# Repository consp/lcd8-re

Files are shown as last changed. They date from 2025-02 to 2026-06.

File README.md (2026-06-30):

# Gui based on lvgl9 for eBikes using a VESC motor controller 

Features:
* customisable (obviously ...)
* Faster update rates than any factory device
* Uses LVGL
* Has MCU with sufficient power and memory to do everything I want it to without too much problems.

## who is this for?

Anyone who wants to build their own eBike display and wants an example. This project is provided as is. No commercial usage is allowed of any kind unless stated explicitly otherwise.

### Who is this not for?

Anyone who expects a ready made product without effort.

## Supported platforms 

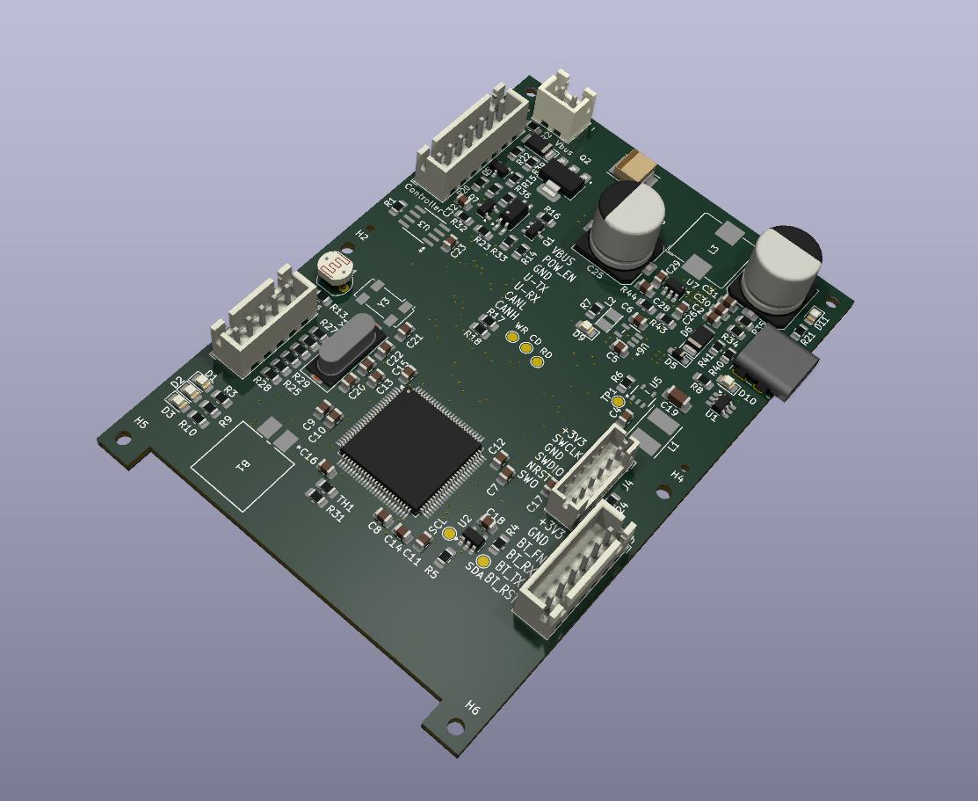
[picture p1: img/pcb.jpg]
Schematic

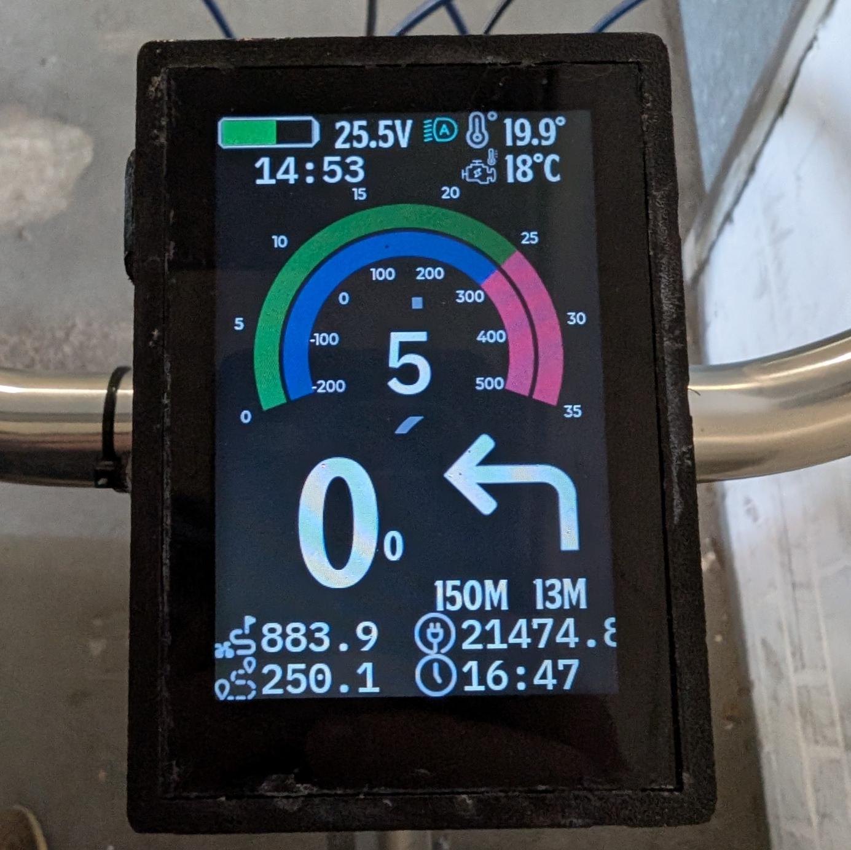
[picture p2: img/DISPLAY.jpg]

- Custom display:
  - Transflective LCD
  - 4 button support
  - Persistent Real time clock (if battery added) 
  - CAN/UART capable
  - Fast
  - Be able to connect to phone to show nav updates (via custom [gadgetbridge app](https://github.com/consp/Gadgetbridge))
  - Connect and use VESC messages ([custom version needed](https://github.com/consp/bldc), [custom tooling needed](https://github.com/consp/vesc-tool))
  - STM32H743
  - Should have enough power to output 1.5A on the 5V rail to USB

## Known issues
Probably many, there is a bug in the PCB making the ADC unreliable when a battery is installed.

# Attribution
Temperature icon: [Temperature Vectors by Vecteezy](https://www.vecteezy.com/free-vector/temperature)
Engine icon: [Heat icons created by HAJICON - Flaticon](https://www.flaticon.com/free-icons/heatv)
Brake icon: [Brake icons created by Smashicons - Flaticon](https://www.flaticon.com/free-icons/brake)
Trip icon: [Trip icons created by improstudio - Flaticon](https://www.flaticon.com/free-icons/trip)
Other icons: [Uicons - Flaticon](https://www.flaticon.com/uicons)
Headlight and headlight auto: [Headlight icons created by TravisAvery - Flaticon](https://www.flaticon.com/free-icon/headlights_9104236)

# License
All stuff not already licenced otherwise is only available under CC-BY-NC-4.0 https://creativecommons.org/licenses/by-nc/4.0/ . For commercial use contact me. No waranty of any kind is provided. No claims of any kind can be made.

# Contribution

If, for some reason, you want to add something or make a pull request: It's fine to do so but don't expect a prompt response. Any LLM based code or other generated files will be rejected without warning.
If, for some reason, you have a question: Use the discussion part of github. Do not expect a prompt response.

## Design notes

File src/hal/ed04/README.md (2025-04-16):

* Mediatek 2502cv 
* GigaDevice HJHJ2115

Pinout buttons

top right view male head on
1 - primary blue - shorts to green

KT unit:

Groen geel zwart rood, Geel groen zwart blauw rood

Rood zwart geel groen blauw

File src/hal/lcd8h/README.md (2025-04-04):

# LCD8 reverse engineering project

Since my LCD8 device fell appart due to the plastic becomming brittile (I guess it's not proper ABS, I'm switching to a bafang anyway) I decided to open it up and see what's going on.

In the end I'm writing my own firmware for it because reasons.

## Board
Front:
Front of PCB
Back:
Back of PCB

### Chips

- U1: MCU AT32F415RCT7, 256k flash
- U2: C1117-3.3 3.3v LDO
- U3: XLSEMI XL7015E1 DC/DC converter 0.8A 5-80V
- U4: 1B0B0G Unknown IC, ~~likely~~ a I2C EEPROM (512 bytes) acts like a standard EEPROM with 2 byte read and 3 byte write. Address is 0x50 looking at the first byte. Only page 1 is ever read.

- Qn: Either G1 or BG (NPN or PNP fet)
- Q?: A1013 PNP Transistor (schematic is wrong), 1A -160V. 

### Notable things
- Beware! The Electrolithic caps might be snot-glued in.
- Bodge cap just north of the MCU
- Place for one more cap on power input on the DC/DC converter.
- Place for one more cap on both VDD and +5V.
- Unconnected 2 pin connector connected to PC0, likely for a non installed button. You could use it for a light sensor as PC0 is an ADC channel.
- Two large pads connected to GND/VBAT, on the USB versions this is where the USB DC/DC converter is connected.
- Two small pads connected by zener to GND/VDD, likely to supply the chip if a RTC low freq. crystal is provided or by using the CINT clock.
- There is a NTC inside the button pcb on channel PC1 (could also be PC2 if installed upside down). It's read normally and acts as a button when pulled to ground.
- Power enable is a very simple "press button and get power", after which the MCU takes over by triggering PA4 (sense for on button is on PA6). This also means the button is at VBAT and the inputs of the other buttons are not protected so make sure they do not short out.
- Power enable will not work with an external sink (e.g. a debugger) attached. 
- The MCU does not like to be power glitched. This will destroy any data in flash memory. (experimentally verified, repeatedly)

- The clock calibration of the internal clock is nonexistant (probably never done), resulting in a 27% in my case (running slow). This also messes up the baudrate calculation and anything over 57k6 will result in bit errors which is probably the reason they stuck with 9k6. Adjusting for this allows higher baudrates.
- To achieve any baudrates over 9k6 you also need to remove the bodgecap added to the RX line. If the baudrate is properly set (or within about 1%) it is never needed anyway.

## Display
The display has the following characteristics:
- 320x480 pixels
- 8080 interface with a ILI9488 chip as display driver.
- 16bit parallel i8080 bus
- 256k colors, recommended to use 64k as the bus is 16bit.

Pinout control lines:
- Pin 9 (PC11) is CS
- Pin 10 (PC10) is DCx (Data/Command select)
- Pin 11 (PC9) is Write Strobe (WRx)
- Pin 12 (PC8) is Read Strobe (RDx)

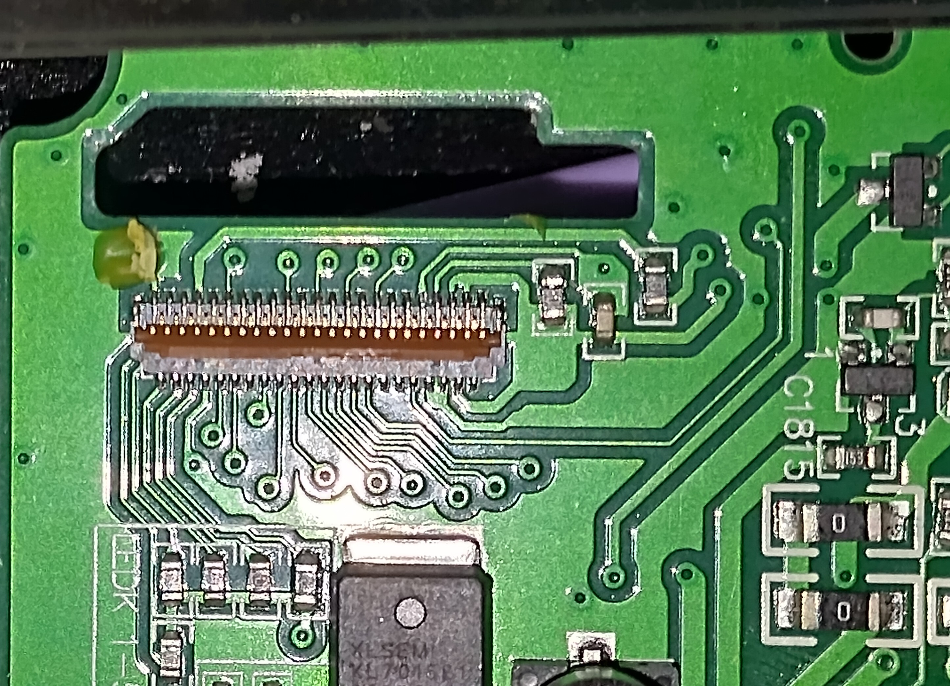
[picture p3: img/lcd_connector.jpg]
LCD connector


Markings display: 
- LM35014B2
- HCC350-06A29
- LM-035CK45021N0-14B2-B1

Markings connector:
- MCU 16B
- RGB 16/18
- BJG-035CK4502N0

The CS is not needed but used by the original firmware. The source contains the gamma setup input copied via logic analyser. The original firmware never reads from the chip but the lines are attached and work.
With no delay states from the MCU the ILI9488 can do ~10MHz when pushing data from memory (~10ns write burst, 90ns delay). In practice it is less but still about 4x the speed of the original firmware.

## Software
The MCU is locked, writing will destroy the original data. BEWARE!

* LVGL 8.4 for most gui parts, can be used 9.x uses a lot more memory resulting is possible tearing (the framebuffer is 32 lines and less results in partial writes of components).
* Raw write for the large letters as lvgl will make buffers for them which eat all the memory (which is not needed anyway).

## Schematic
My poor attempt at drawing a schematic.
Schematic

# License
All stuff not already licenced otherwise is only available under CC-BY-NC-4.0 https://creativecommons.org/licenses/by-nc/4.0/ . For commercial use contact me.

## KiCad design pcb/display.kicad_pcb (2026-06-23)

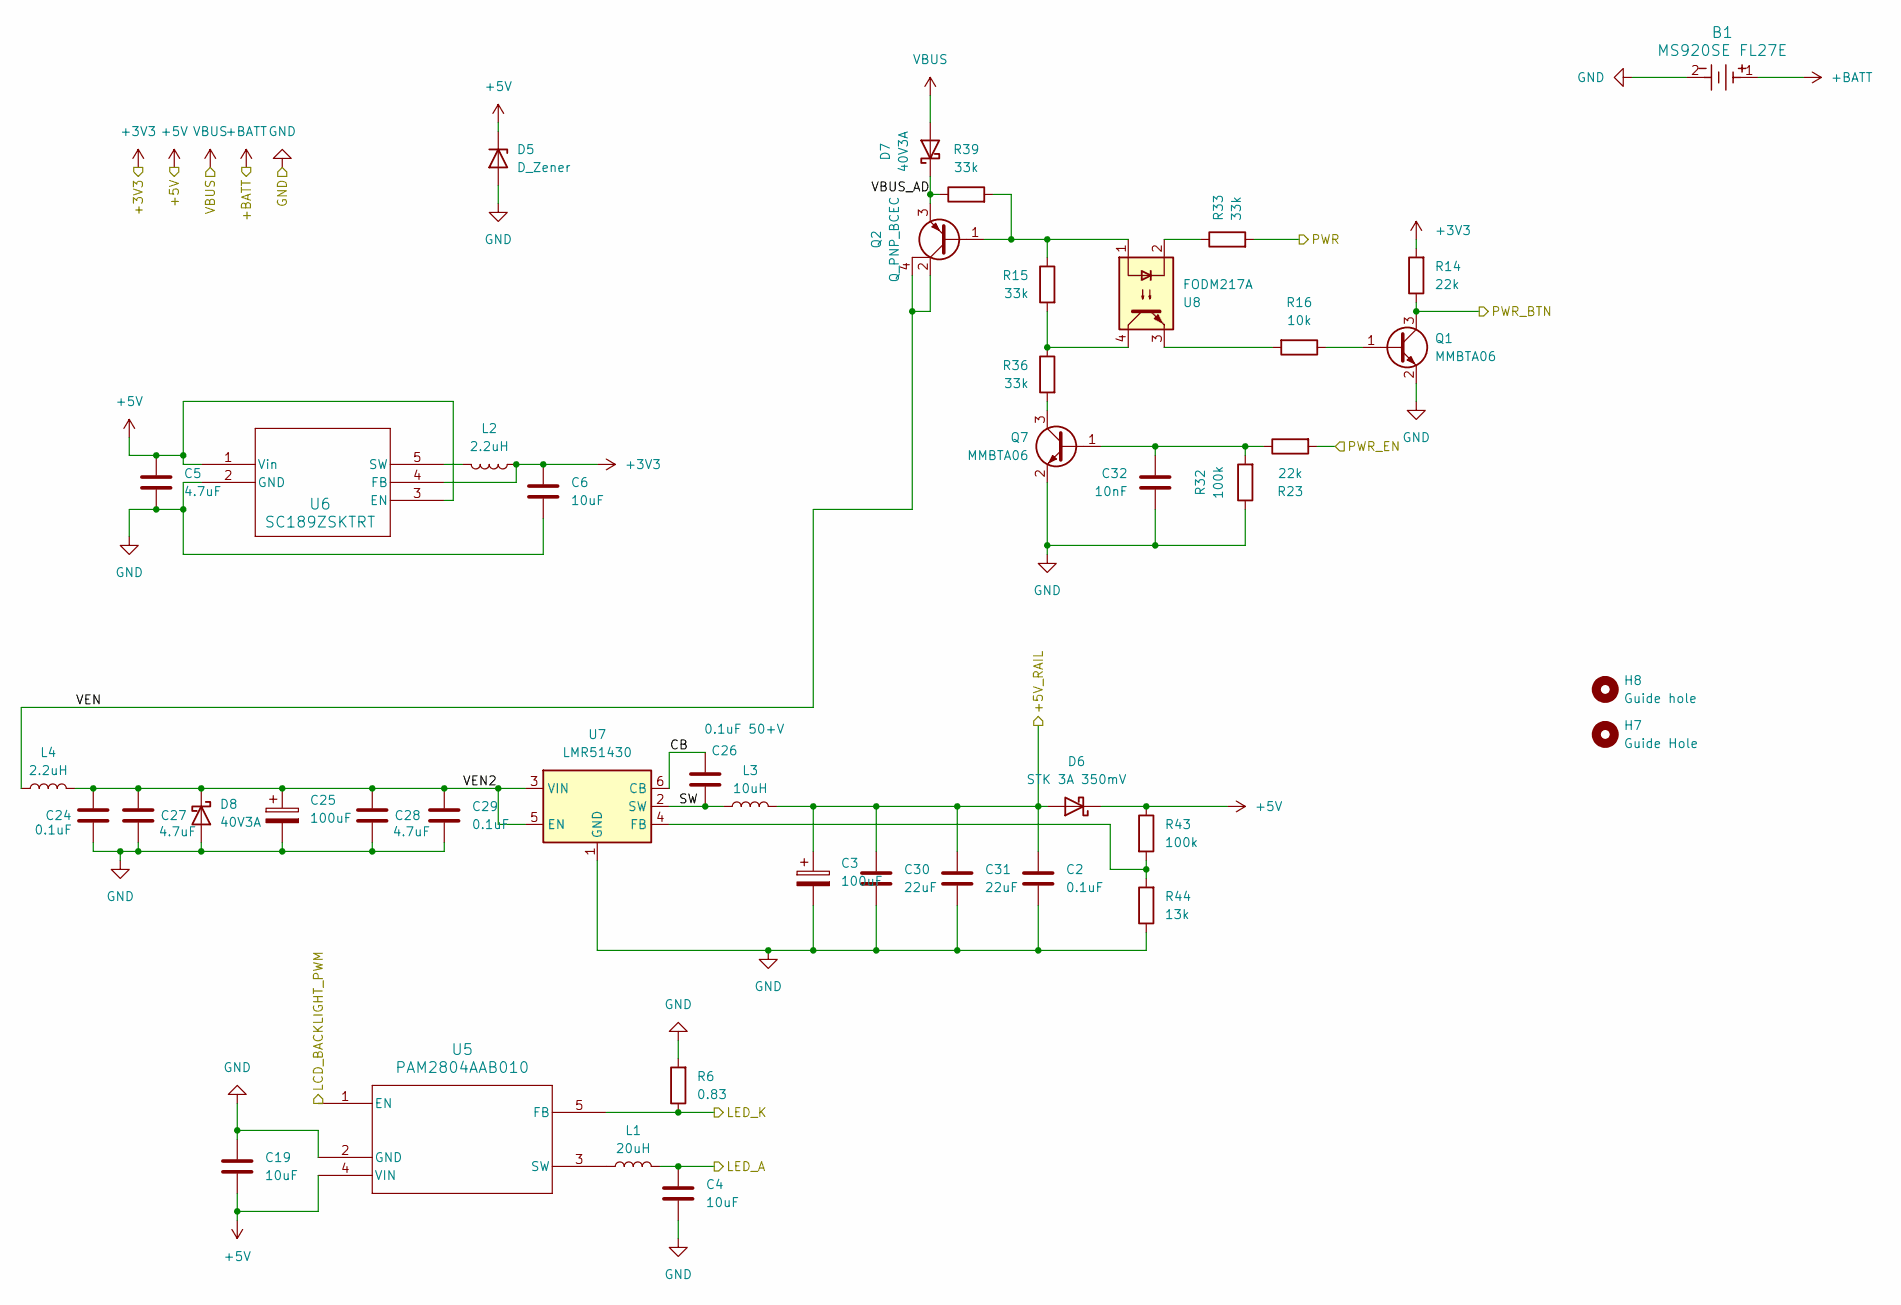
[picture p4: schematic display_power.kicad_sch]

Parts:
B1: MS920SE FL27E; BATT_MS920SE_FL27E_SEI
C2: 0.1uF; C_0805_2012Metric
C3, C25: 100uF; CP_Elec_10x10.5
C4, C6: 10uF; C_0805_2012Metric
C5: 4.7uF; C_0805_2012Metric
C19: 10uF; C_1206_3216Metric_Pad1.33x1.80mm_HandSolder
C24, C29: 0.1uF; C_0805_2012Metric_Pad1.18x1.45mm_HandSolder
C26: 0.1uF 50+V; C_0805_2012Metric_Pad1.18x1.45mm_HandSolder
C27, C28: 4.7uF; C_0805_2012Metric_Pad1.18x1.45mm_HandSolder
C30, C31: 22uF; C_0805_2012Metric_Pad1.18x1.45mm_HandSolder
C32: 10nF; C_0805_2012Metric
D5: D_Zener; D_SOD-323_HandSoldering
D6: STK 3A 350mV; D_SOD-128
D7: 40V3A; D_SOD-128
D8: 40V3A; D_SOD-123
H7: Guide Hole; ToolingHole_1.152mm
H8: Guide hole; ToolingHole_1.152mm
L1: 20uH; L_Taiyo-Yuden_NR-50xx_HandSoldering
L2: 2.2uH; L_Taiyo-Yuden_NR-20xx_HandSoldering
L3: 10uH; L_Bourns_SRP1038C_10.0x10.0mm
L4: 2.2uH; L_Taiyo-Yuden_NR-50xx_HandSoldering
Q1, Q7: MMBTA06; SOT-23
Q2: Q_PNP_BCEC; SOT-223-3_TabPin2
R6: 0.83; R_0805_2012Metric_Pad1.20x1.40mm_HandSolder
R14, R23: 22k; R_0805_2012Metric_Pad1.20x1.40mm_HandSolder
R15, R33, R36, R39: 33k; R_0805_2012Metric_Pad1.20x1.40mm_HandSolder
R16: 10k; R_0805_2012Metric_Pad1.20x1.40mm_HandSolder
R32, R43: 100k; R_0805_2012Metric_Pad1.20x1.40mm_HandSolder
R44: 13k; R_0805_2012Metric_Pad1.20x1.40mm_HandSolder
U5: PAM2804AAB010; PAM2804_DIO
U6: SC189ZSKTRT; MF05A_TEX
U7: LMR51430; SOT-23-6
U8: FODM217A; SOP-4_4.4x2.6mm_P1.27mm

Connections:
+3V3: C6.1, L2.1, R14.2, U6.4 (FB); also elsewhere on the board
+5V: C5.1, C19.2, D5.1 (K), D6.1 (K), R43.1, U5.4 (VIN), U6.1 (Vin), U6.3 (EN); also elsewhere on the board
+BATT: B1.1; also elsewhere on the board
/Connectors/LED_A: C4.1, L1.2; also elsewhere on the board
/Connectors/LED_K: R6.1, U5.5 (FB); also elsewhere on the board
/Connectors/PWR: R33.2; also elsewhere on the board
/MCU/LCD_BACKLIGHT_PWM: U5.1 (EN); also elsewhere on the board
/MCU/PWR_BTN: Q1.3 (C), R14.1; also elsewhere on the board
/MCU/PWR_EN: R23.2; also elsewhere on the board
/Other/+5V_RAIL: C2.1, C3.1, C30.1, C31.1, D6.2 (A), L3.2; also elsewhere on the board
/Power/CB: C26.1, U7.6 (CB)
/Power/SW: C26.2, L3.1, U7.2 (SW)
/Power/VBUS_AD: D7.1 (K), Q2.3 (E), R39.1
/Power/VEN: L4.1, Q2.2 (C), Q2.4 (C)
/Power/VEN2: C24.1, C25.1, C27.1, C28.1, C29.1, D8.1 (K), L4.2, U7.3 (VIN), U7.5 (EN)
GND: B1.2, C2.2, C3.2, C4.2, C5.2, C6.2, C19.1, C24.2, C25.2, C27.2, C28.2, C29.2, C30.2, C31.2, C32.2, D5.2 (A), D8.2 (A), Q1.2 (E), Q7.2 (E), R6.2, R32.1, R44.1, U5.2 (GND), U6.2 (GND), U7.1 (GND); also elsewhere on the board
unnamed: Q1.1 (B), R16.1
unnamed: Q2.1 (B), R15.1, R39.2, U8.1
unnamed: C32.1, Q7.1 (B), R23.1, R32.2
unnamed: Q7.3 (C), R36.2
unnamed: R15.2, R36.1, U8.4
unnamed: R16.2, U8.3
unnamed: R33.1, U8.2
unnamed: L1.1, U5.3 (SW)
unnamed: L2.2, U6.5 (SW)
unnamed: R43.2, R44.2, U7.4 (FB)
VBUS: D7.2 (A); also elsewhere on the board

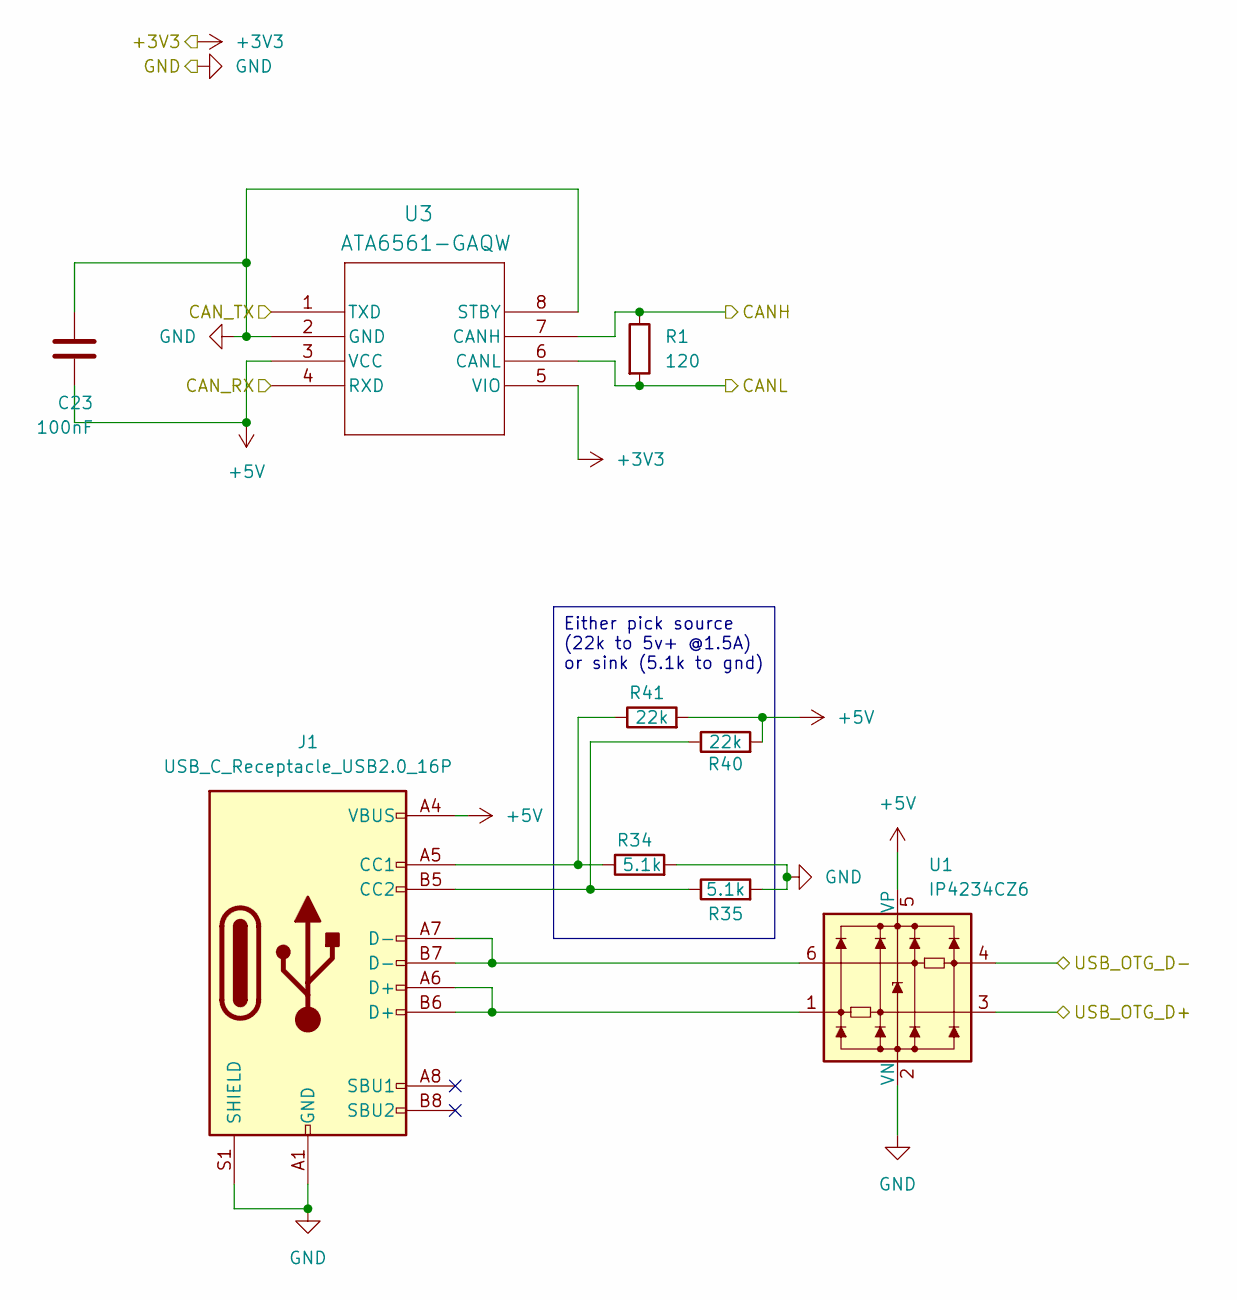
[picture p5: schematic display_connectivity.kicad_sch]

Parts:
C23: 100nF; C_0805_2012Metric
J1: USB_C_Receptacle_USB2.0_16P; USB_C_Receptacle_GCT_USB4085
R1: 120; R_0805_2012Metric_Pad1.20x1.40mm_HandSolder
R34, R35: 5.1k; R_0805_2012Metric
R40, R41: 22k; R_0805_2012Metric
U1: IP4234CZ6; SC-74-6_1.55x2.9mm_P0.95mm
U3: ATA6561-GAQW; SOIC8_4P9X3P9MC_MCH

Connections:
+3V3: U3.5 (VIO); also elsewhere on the board
+5V: C23.1, J1.A4 (VBUS), J1.A9 (VBUS), J1.B4 (VBUS), J1.B9 (VBUS), R40.2, R41.2, U1.5 (VP), U3.3 (VCC); also elsewhere on the board
/Connectivity/CANH: R1.1, U3.7 (CANH); also elsewhere on the board
/Connectivity/CANL: R1.2, U3.6 (CANL); also elsewhere on the board
/Connectivity/CAN_RX: U3.4 (RXD); also elsewhere on the board
/Connectivity/CAN_TX: U3.1 (TXD); also elsewhere on the board
/Connectivity/USB_OTG_D+: U1.3; also elsewhere on the board
/Connectivity/USB_OTG_D-: U1.4; also elsewhere on the board
GND: C23.2, J1.A1 (GND), J1.A12 (GND), J1.B1 (GND), J1.B12 (GND), J1.S1 (SHIELD), R34.2, R35.2, U1.2 (VN), U3.2 (GND), U3.8 (STBY); also elsewhere on the board
unnamed: J1.A5 (CC1), R34.1, R41.1
unnamed: J1.B5 (CC2), R35.1, R40.1
unnamed: J1.A6 (D+), J1.B6 (D+), U1.1
unnamed: J1.A7 (D-), J1.B7 (D-), U1.6

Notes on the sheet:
Either pick source (22k to 5v+ @1.5A) or sink (5.1k to gnd)

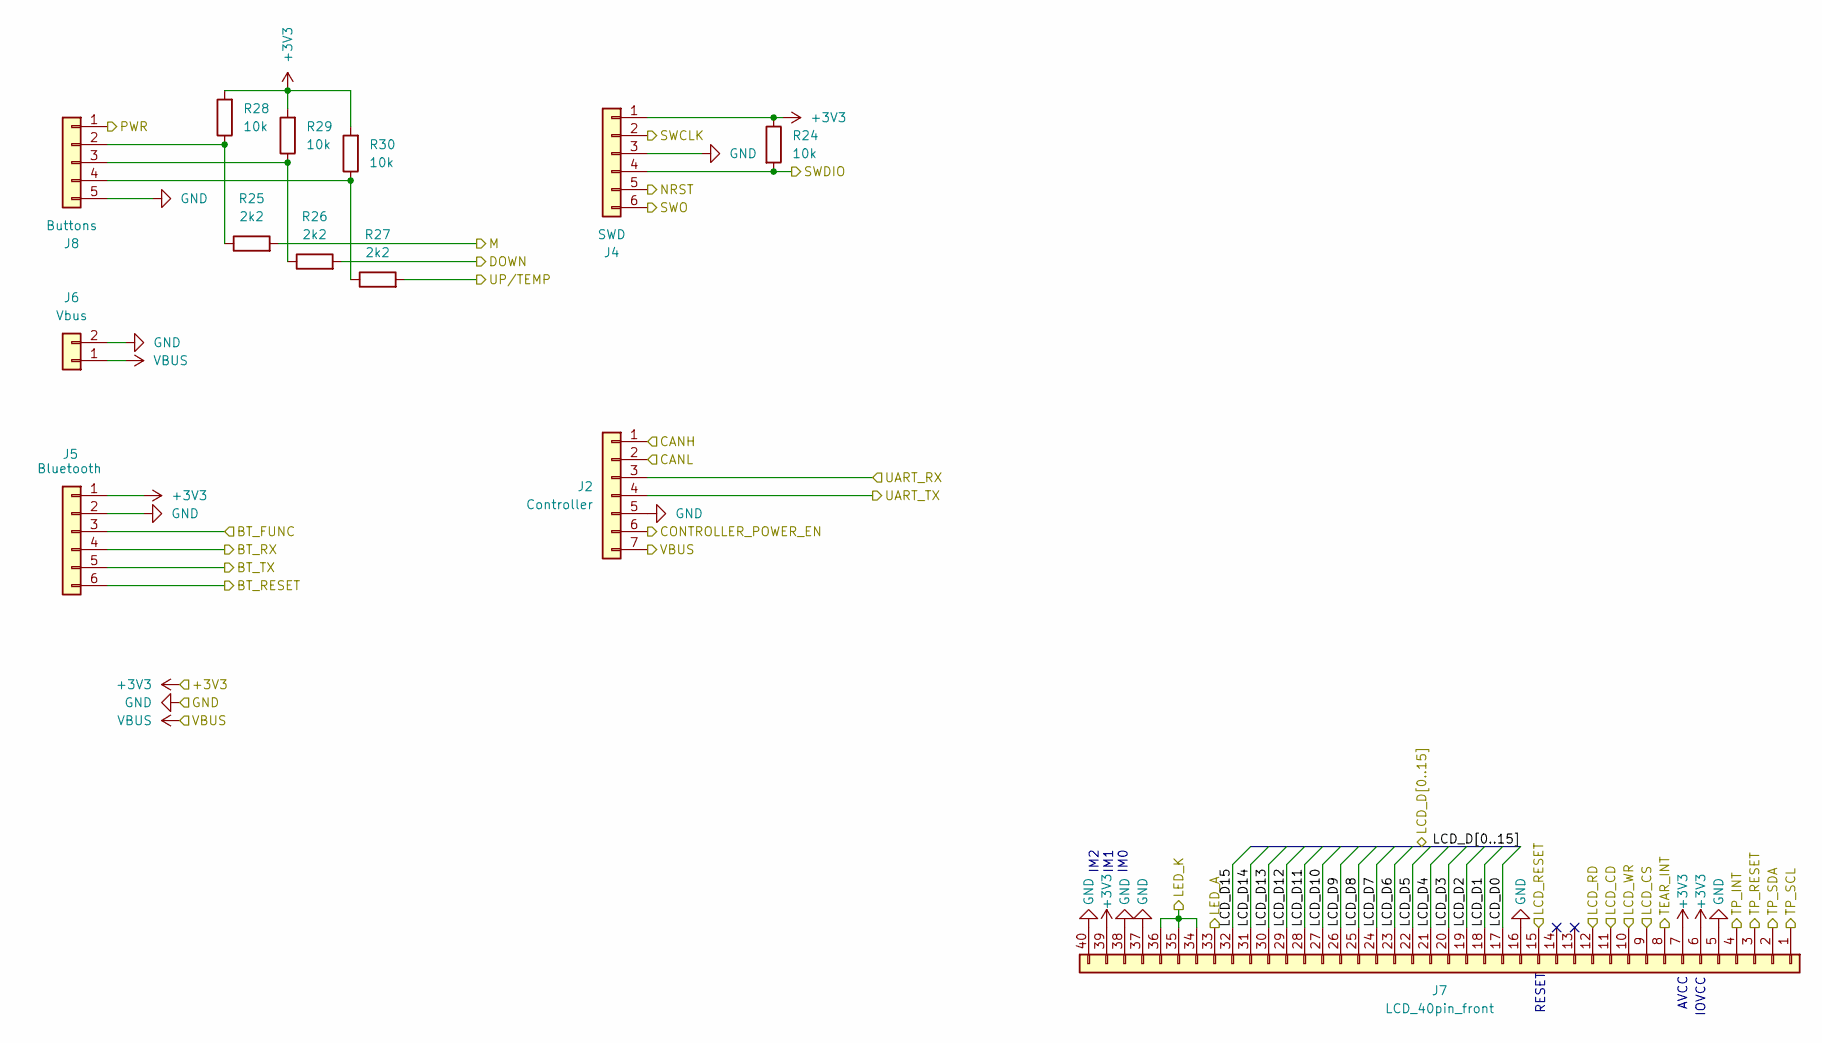
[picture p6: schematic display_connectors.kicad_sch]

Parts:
J2: Controller; JST_XH_B7B-XH-A_1x07_P2.50mm_Vertical
J4: SWD; JST_PH_B6B-PH-K_1x06_P2.00mm_Vertical
J5: Bluetooth; JST_XH_B6B-XH-A_1x06_P2.50mm_Vertical
J6: Vbus; JST_XH_B2B-XH-A_1x02_P2.50mm_Vertical
J7: LCD_40pin_front; Hirose_FH12-40S-0.5SH_1x40-1MP_P0.50mm_Horizontal
J8: Buttons; JST_XH_B5B-XH-A_1x05_P2.50mm_Vertical
R24, R28, R29, R30: 10k; R_0805_2012Metric_Pad1.20x1.40mm_HandSolder
R25, R26, R27: 2k2; R_0805_2012Metric_Pad1.20x1.40mm_HandSolder

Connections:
+3V3: J4.1, J5.1, J7.6, J7.7, J7.39, R24.1, R28.2, R29.2, R30.2; also elsewhere on the board
/Connectivity/CANH: J2.1; also elsewhere on the board
/Connectivity/CANL: J2.2; also elsewhere on the board
/Connectors/BT_FUNC: J5.3; also elsewhere on the board
/Connectors/BT_RESET: J5.6; also elsewhere on the board
/Connectors/BT_RX: J5.4; also elsewhere on the board
/Connectors/BT_TX: J5.5; also elsewhere on the board
/Connectors/CONTROLLER_POWER_EN: J2.6; also elsewhere on the board
/Connectors/LCD_CS: J7.9; also elsewhere on the board
/Connectors/LCD_D0: J7.17; also elsewhere on the board
/Connectors/LCD_D1: J7.18; also elsewhere on the board
/Connectors/LCD_D2: J7.19; also elsewhere on the board
/Connectors/LCD_D3: J7.20; also elsewhere on the board
/Connectors/LCD_D4: J7.21; also elsewhere on the board
/Connectors/LCD_D5: J7.22; also elsewhere on the board
/Connectors/LCD_D6: J7.23; also elsewhere on the board
/Connectors/LCD_D7: J7.24; also elsewhere on the board
/Connectors/LCD_D8: J7.25; also elsewhere on the board
/Connectors/LCD_D9: J7.26; also elsewhere on the board
/Connectors/LCD_D10: J7.27; also elsewhere on the board
/Connectors/LCD_D11: J7.28; also elsewhere on the board
/Connectors/LCD_D12: J7.29; also elsewhere on the board
/Connectors/LCD_D13: J7.30; also elsewhere on the board
/Connectors/LCD_D14: J7.31; also elsewhere on the board
/Connectors/LCD_D15: J7.32; also elsewhere on the board
/Connectors/LED_A: J7.33; also elsewhere on the board
/Connectors/LED_K: J7.34, J7.35, J7.36; also elsewhere on the board
/Connectors/PWR: J8.1; also elsewhere on the board
/Connectors/SWCLK: J4.2; also elsewhere on the board
/Connectors/SWDIO: J4.4, R24.2; also elsewhere on the board
/Connectors/SWO: J4.6; also elsewhere on the board
/Connectors/TEAR_INT: J7.8; also elsewhere on the board
/Connectors/TP_INT: J7.4; also elsewhere on the board
/Connectors/TP_RESET: J7.3; also elsewhere on the board
/Connectors/TP_SCL: J7.1; also elsewhere on the board
/Connectors/TP_SDA: J7.2; also elsewhere on the board
/Connectors/UART_RX: J2.3; also elsewhere on the board
/Connectors/UART_TX: J2.4; also elsewhere on the board
/MCU/DOWN: R26.2; also elsewhere on the board
/MCU/LCD_CD: J7.11; also elsewhere on the board
/MCU/LCD_RD: J7.12; also elsewhere on the board
/MCU/LCD_WR: J7.10; also elsewhere on the board
/MCU/M: R25.2; also elsewhere on the board
/MCU/NRST: J4.5, J7.15; also elsewhere on the board
/MCU/UP/TEMP: R27.2; also elsewhere on the board
GND: J2.5, J4.3, J5.2, J6.2, J7.5, J7.16, J7.37, J7.38, J7.40, J8.5; also elsewhere on the board
unnamed: J8.2, R25.1, R28.1
unnamed: J8.3, R26.1, R29.1
unnamed: J8.4, R27.1, R30.1
VBUS: J2.7, J6.1; also elsewhere on the board

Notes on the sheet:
AVCC
RESET
IOVCC
IM2 IM1 IM0

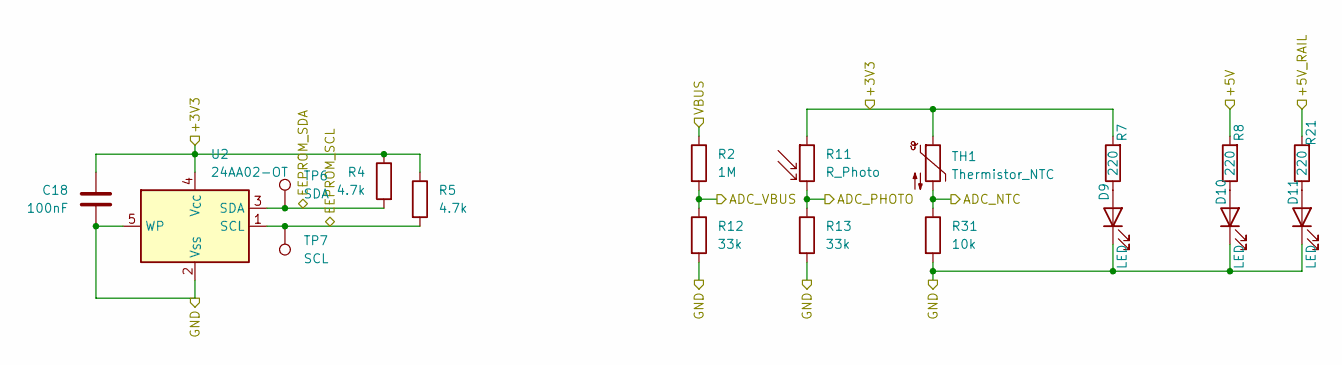
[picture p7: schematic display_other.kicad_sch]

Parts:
C18: 100nF; C_0805_2012Metric
D9, D10, D11: LED; LED_0805_2012Metric_Pad1.15x1.40mm_HandSolder
R2: 1M; R_0805_2012Metric_Pad1.20x1.40mm_HandSolder
R4, R5: 4.7k; R_0805_2012Metric_Pad1.20x1.40mm_HandSolder
R7, R8, R21: 220; R_0805_2012Metric_Pad1.20x1.40mm_HandSolder
R11: R_Photo; R_LDR_5.1x4.3mm_P3.4mm_Vertical
R12, R13: 33k; R_0805_2012Metric_Pad1.20x1.40mm_HandSolder
R31: 10k; R_0805_2012Metric_Pad1.20x1.40mm_HandSolder
TH1: Thermistor_NTC; R_0805_2012Metric_Pad1.20x1.40mm_HandSolder
TP6: SDA; TestPoint_Pad_D1.5mm
TP7: SCL; TestPoint_Pad_D1.5mm
U2: 24AA02-OT; SOT-23-5

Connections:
+3V3: C18.2, R4.1, R5.1, R7.2, R11.1, TH1.1, U2.4 (V_{CC}); also elsewhere on the board
+5V: R8.2; also elsewhere on the board
/MCU/ADC_NTC: R31.1, TH1.2; also elsewhere on the board
/MCU/ADC_VBUS: R2.2, R12.1; also elsewhere on the board
/MCU/ADH_PHOTO: R11.2, R13.1; also elsewhere on the board
/MCU/EEPROM_SCA: R4.2, TP6.1, U2.3 (SDA); also elsewhere on the board
/MCU/EEPROM_SCL: R5.2, TP7.1, U2.1 (SCL); also elsewhere on the board
/Other/+5V_RAIL: R21.2; also elsewhere on the board
GND: C18.1, D9.1 (K), D10.1 (K), D11.1 (K), R12.2, R13.2, R31.2, U2.2 (V_{SS}), U2.5 (WP); also elsewhere on the board
unnamed: D9.2 (A), R7.1
unnamed: D10.2 (A), R8.1
unnamed: D11.2 (A), R21.1
VBUS: R2.1; also elsewhere on the board

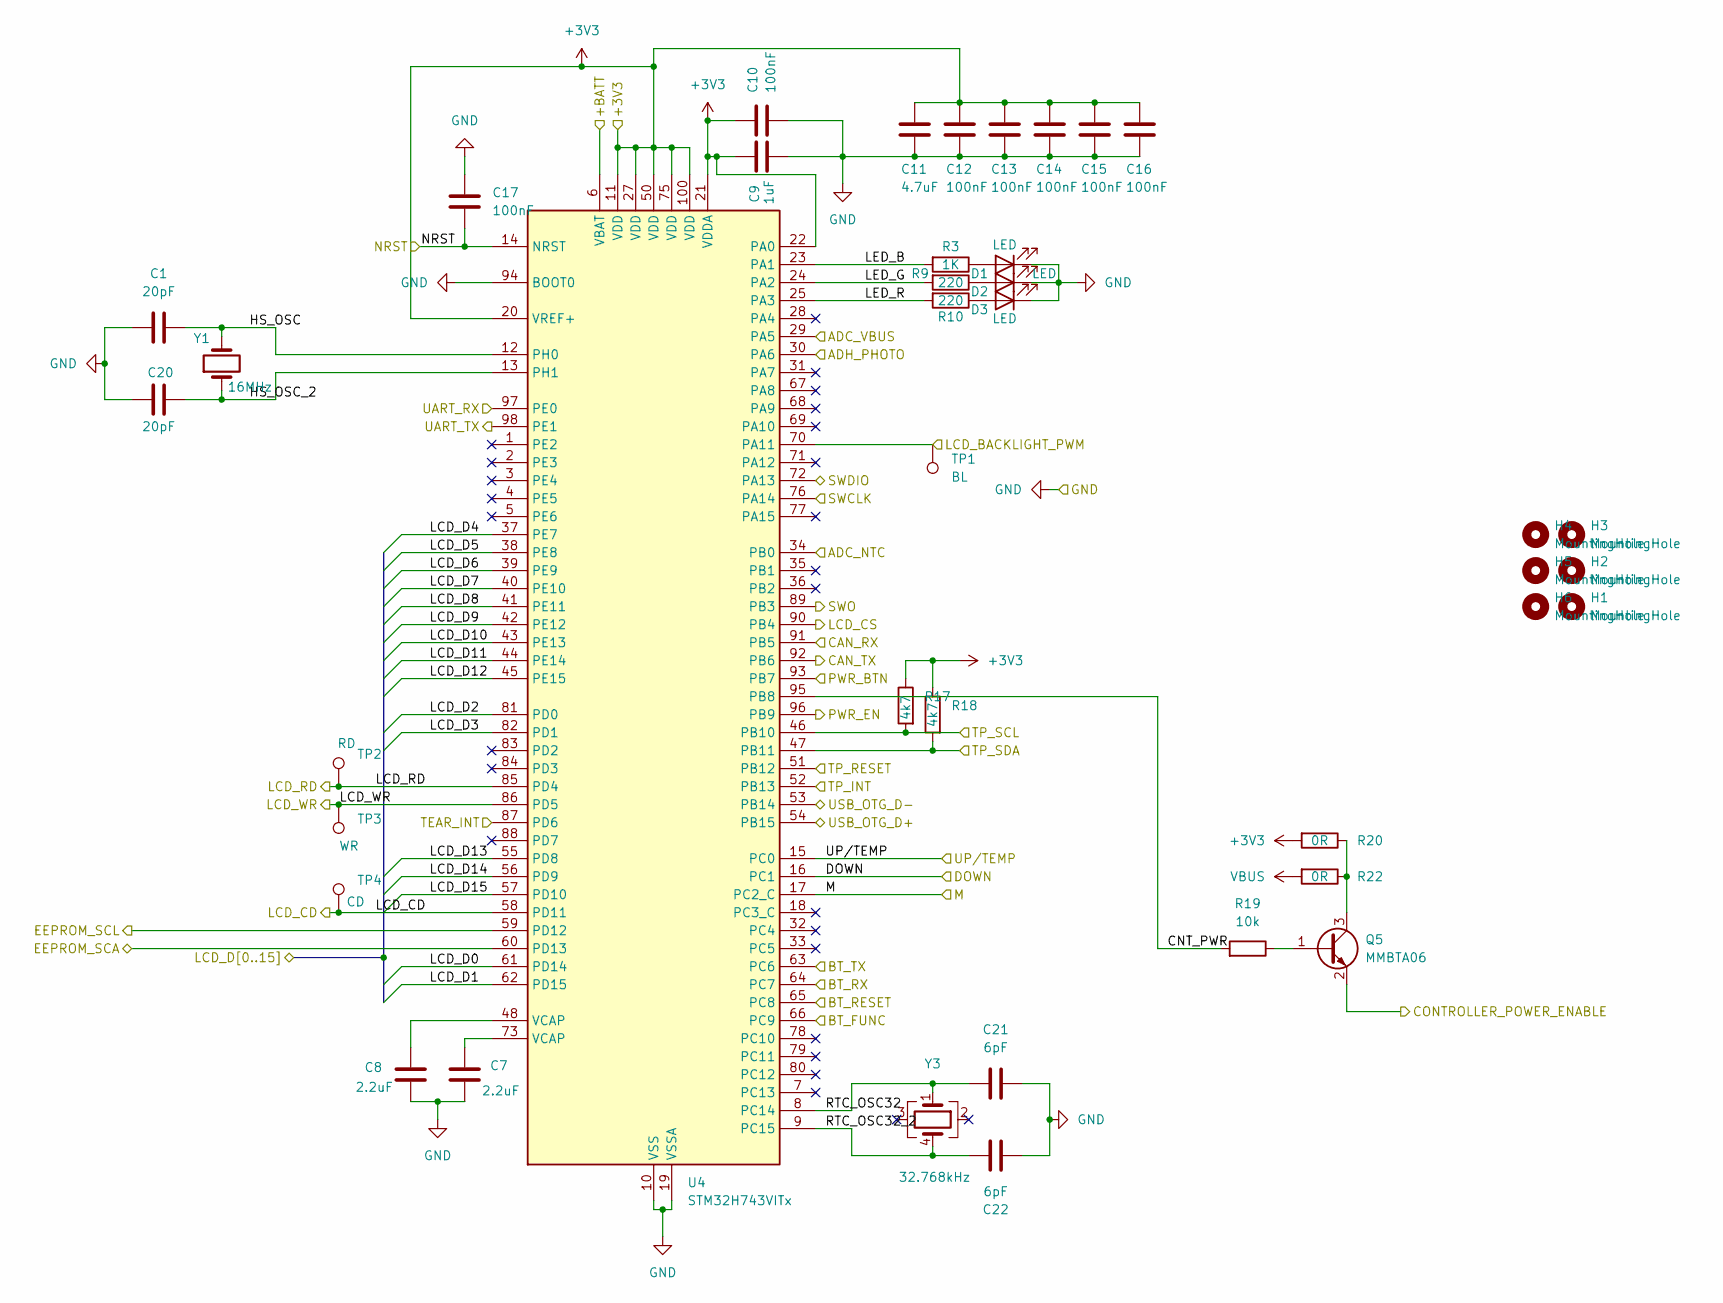
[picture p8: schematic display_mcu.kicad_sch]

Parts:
C1: 20pF; C_0805_2012Metric
C7, C8: 2.2uF; C_0805_2012Metric
C9: 1uF; C_0805_2012Metric
C10, C12, C13, C14, C15, C16, C17: 100nF; C_0805_2012Metric
C11: 4.7uF; C_0805_2012Metric
C20: 20pF; C_0805_2012Metric_Pad1.18x1.45mm_HandSolder
C21, C22: 6pF; C_0805_2012Metric_Pad1.18x1.45mm_HandSolder
D1, D2, D3: LED; LED_0805_2012Metric_Pad1.15x1.40mm_HandSolder
H1, H2, H3, H4, H5, H6: MountingHole; MountingHole_2.2mm_M2
Q5: MMBTA06; SOT-23
R3: 1K; R_0805_2012Metric_Pad1.20x1.40mm_HandSolder
R9, R10: 220; R_0805_2012Metric_Pad1.20x1.40mm_HandSolder
R17, R18: 4k7; R_0805_2012Metric_Pad1.20x1.40mm_HandSolder
R19: 10k; R_0805_2012Metric_Pad1.20x1.40mm_HandSolder
R20, R22: 0R; R_0805_2012Metric_Pad1.20x1.40mm_HandSolder
TP1: BL; TestPoint_Pad_D1.5mm
TP2: RD; TestPoint_Pad_D1.5mm
TP3: WR; TestPoint_Pad_D1.5mm
TP4: CD; TestPoint_Pad_D1.5mm
U4: STM32H743VITx; LQFP-100_14x14mm_P0.5mm
Y1: 16MHz; Crystal_SMD_HC49-SD
Y3: 32.768kHz; Crystal_SMD_Abracon_ABS25-4Pin_8.0x3.8mm

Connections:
+3V3: C9.1, C10.1, C11.2, C12.2, C13.2, C14.2, C15.2, C16.2, R17.1, R18.1, R20.2, U4.11 (VDD), U4.20 (VREF+), U4.21 (VDDA), U4.22 (PA0), U4.27 (VDD), U4.50 (VDD), U4.75 (VDD), U4.100 (VDD); also elsewhere on the board
+BATT: U4.6 (VBAT); also elsewhere on the board
/Connectivity/CAN_RX: U4.91 (PB5); also elsewhere on the board
/Connectivity/CAN_TX: U4.92 (PB6); also elsewhere on the board
/Connectivity/USB_OTG_D+: U4.54 (PB15); also elsewhere on the board
/Connectivity/USB_OTG_D-: U4.53 (PB14); also elsewhere on the board
/Connectors/BT_FUNC: U4.66 (PC9); also elsewhere on the board
/Connectors/BT_RESET: U4.65 (PC8); also elsewhere on the board
/Connectors/BT_RX: U4.64 (PC7); also elsewhere on the board
/Connectors/BT_TX: U4.63 (PC6); also elsewhere on the board
/Connectors/CONTROLLER_POWER_EN: Q5.2 (E); also elsewhere on the board
/Connectors/LCD_CS: U4.90 (PB4); also elsewhere on the board
/Connectors/LCD_D0: U4.61 (PD14); also elsewhere on the board
/Connectors/LCD_D1: U4.62 (PD15); also elsewhere on the board
/Connectors/LCD_D2: U4.81 (PD0); also elsewhere on the board
/Connectors/LCD_D3: U4.82 (PD1); also elsewhere on the board
/Connectors/LCD_D4: U4.37 (PE7); also elsewhere on the board
/Connectors/LCD_D5: U4.38 (PE8); also elsewhere on the board
/Connectors/LCD_D6: U4.39 (PE9); also elsewhere on the board
/Connectors/LCD_D7: U4.40 (PE10); also elsewhere on the board
/Connectors/LCD_D8: U4.41 (PE11); also elsewhere on the board
/Connectors/LCD_D9: U4.42 (PE12); also elsewhere on the board
/Connectors/LCD_D10: U4.43 (PE13); also elsewhere on the board
/Connectors/LCD_D11: U4.44 (PE14); also elsewhere on the board
/Connectors/LCD_D12: U4.45 (PE15); also elsewhere on the board
/Connectors/LCD_D13: U4.55 (PD8); also elsewhere on the board
/Connectors/LCD_D14: U4.56 (PD9); also elsewhere on the board
/Connectors/LCD_D15: U4.57 (PD10); also elsewhere on the board
/Connectors/SWCLK: U4.76 (PA14); also elsewhere on the board
/Connectors/SWDIO: U4.72 (PA13); also elsewhere on the board
/Connectors/SWO: U4.89 (PB3); also elsewhere on the board
/Connectors/TEAR_INT: U4.87 (PD6); also elsewhere on the board
/Connectors/TP_INT: U4.52 (PB13); also elsewhere on the board
/Connectors/TP_RESET: U4.51 (PB12); also elsewhere on the board
/Connectors/TP_SCL: R17.2, U4.46 (PB10); also elsewhere on the board
/Connectors/TP_SDA: R18.2, U4.47 (PB11); also elsewhere on the board
/Connectors/UART_RX: U4.97 (PE0); also elsewhere on the board
/Connectors/UART_TX: U4.98 (PE1); also elsewhere on the board
/MCU/ADC_NTC: U4.34 (PB0); also elsewhere on the board
/MCU/ADC_VBUS: U4.29 (PA5); also elsewhere on the board
/MCU/ADH_PHOTO: U4.30 (PA6); also elsewhere on the board
/MCU/CNT_PWR: R19.2, U4.95 (PB8)
/MCU/DOWN: U4.16 (PC1); also elsewhere on the board
/MCU/EEPROM_SCA: U4.60 (PD13); also elsewhere on the board
/MCU/EEPROM_SCL: U4.59 (PD12); also elsewhere on the board
/MCU/HS_OSC: C1.1, U4.12 (PH0), Y1.2
/MCU/HS_OSC_2: C20.2, U4.13 (PH1), Y1.1
/MCU/LCD_BACKLIGHT_PWM: TP1.1, U4.70 (PA11); also elsewhere on the board
/MCU/LCD_CD: TP4.1, U4.58 (PD11); also elsewhere on the board
/MCU/LCD_RD: TP2.1, U4.85 (PD4); also elsewhere on the board
/MCU/LCD_WR: TP3.1, U4.86 (PD5); also elsewhere on the board
/MCU/LED_B: R3.2, U4.23 (PA1)
/MCU/LED_G: R9.2, U4.24 (PA2)
/MCU/LED_R: R10.2, U4.25 (PA3)
/MCU/M: U4.17 (PC2_C); also elsewhere on the board
/MCU/NRST: C17.2, U4.14 (NRST); also elsewhere on the board
/MCU/PWR_BTN: U4.93 (PB7); also elsewhere on the board
/MCU/PWR_EN: U4.96 (PB9); also elsewhere on the board
/MCU/RTC_OSC32: C21.1, U4.8 (PC14), Y3.1
/MCU/RTC_OSC32_2: C22.2, U4.9 (PC15), Y3.4
/MCU/UP/TEMP: U4.15 (PC0); also elsewhere on the board
GND: C1.2, C7.2, C8.2, C9.2, C10.2, C11.1, C12.1, C13.1, C14.1, C15.1, C16.1, C17.1, C20.1, C21.2, C22.1, D1.1 (K), D2.1 (K), D3.1 (K), U4.10 (VSS), U4.19 (VSSA), U4.26 (VSS), U4.49 (VSS), U4.74 (VSS), U4.94 (BOOT0), U4.99 (VSS); also elsewhere on the board
unnamed: C7.1, U4.73 (VCAP)
unnamed: C8.1, U4.48 (VCAP)
unnamed: D1.2 (A), R3.1
unnamed: D2.2 (A), R9.1
unnamed: D3.2 (A), R10.1
unnamed: Q5.1 (B), R19.1
unnamed: Q5.3 (C), R20.1, R22.1
VBUS: R22.2; also elsewhere on the board

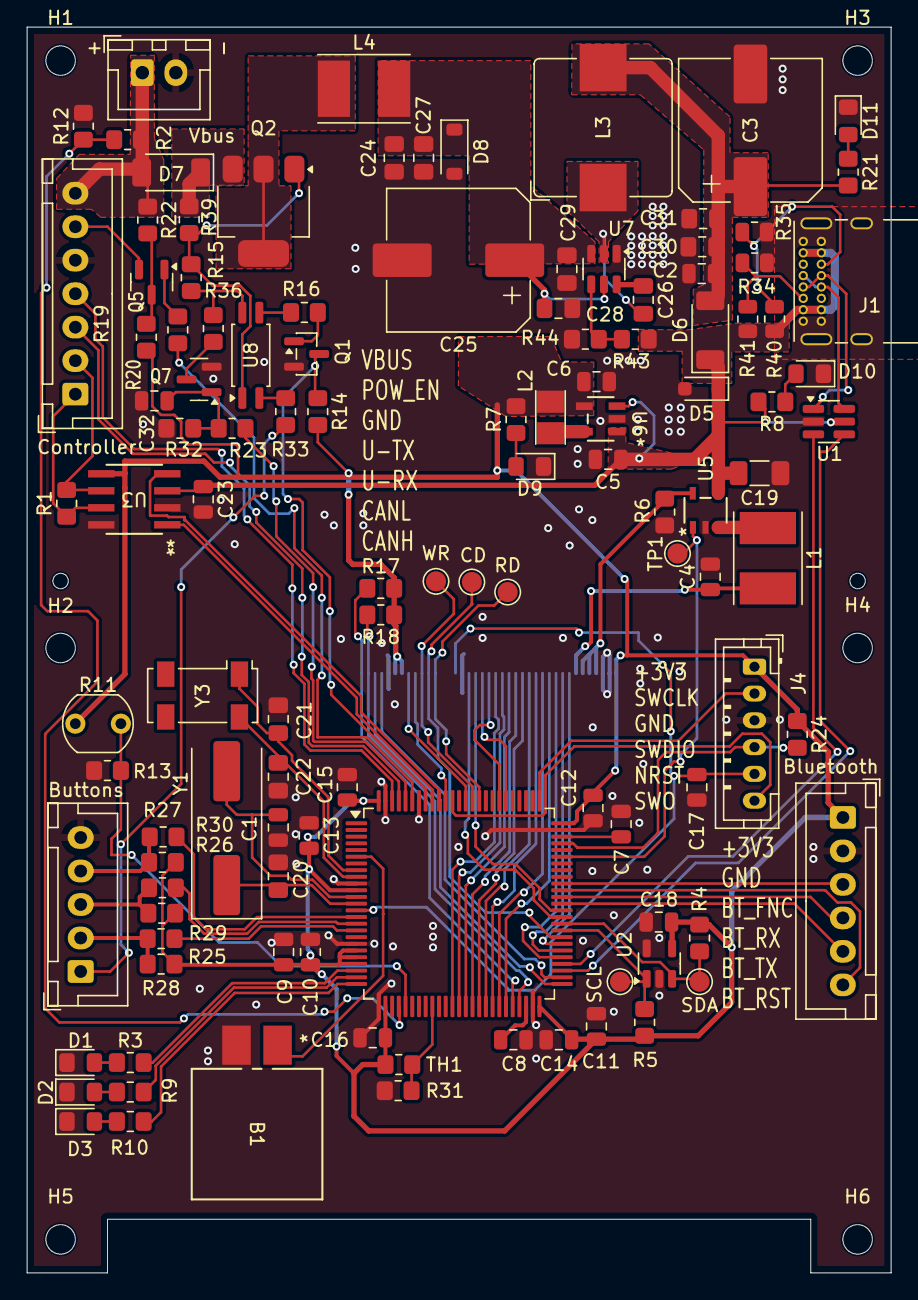
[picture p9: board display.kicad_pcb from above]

Board: 2 copper layers, 64.5 x 93.0 mm, 124 parts (1 on the bottom side), 102 nets.

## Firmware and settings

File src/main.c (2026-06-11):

/**
  **************************************************************************
  * @file     main.c
  * @brief    main program
  **************************************************************************
  *                       Copyright notice & Disclaimer
  *
  * The software Board Support Package (BSP) that is made available to
  * download from Artery official website is the copyrighted work of Artery.
  * Artery authorizes customers to use, copy, and distribute the BSP
  * software and its related documentation for the purpose of design and
  * development in conjunction with Artery microcontrollers. Use of the
  * software is governed by this copyright notice and the following disclaimer.
  *
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
  **************************************************************************
  */
#define LOOP 1
#include <string.h>
#include <stdio.h>
#include "config.h"
#ifndef PLATFORM_SIM
 #if defined(AT32F415)
  #include "at32f415.h"
  #include "at32f415_clock.h"
  #include <cmsis/core/core_cm4.h>
 #elif defined(AT32F435)
  #include "at32f435_437.h"
  #include <cmsis/core/core_cm4.h>
 #elif defined(STM32H743)
  #include "stm32h7xx.h"
  #include <cmsis/core/core_cm7.h>
 #endif
#endif
#ifdef PLATFORM_SIM
#include <SDL_timer.h>
#endif

#include "lcd.h"
#include "delay.h"
#include "eeprom.h"
#include "controls.h"
#include "gui.h"
#include "uart.h"
#include "clock.h"
#include "crc.h"
#include "comm.h"
#include "uart.h"
#include "can.h"

#ifdef SEGGER_RTT
#include "rtt/SEGGER_RTT.h"
#endif

extern lv_display_t *display;
extern volatile uint32_t shutdown_timer;
extern settings_t settings;
extern int mconf_actual;
extern int mconf_updated;
/**
  * @brief  main function.
  * @param  none
  * @retval none
  */

#if (!defined(DIRECT) || (defined(DIRECT) && defined(PARTIAL)))
extern uint8_t pixelbuffer[], pixelbuffer2[];
#else
extern uint8_t framebuffer[];
#endif
#ifdef MEMPOOL
extern uint8_t mempool[];
#endif

#if defined(SEMIHOSTING) && !defined(PLATFORM_SIM)
extern void initialise_monitor_handles(void);
#endif

#if defined(SWO)
extern int __io_getchar(void) __attribute__((weak));
int __io_putchar(int ch)
{
    ITM_SendChar(ch);
    return(ch);
}

__attribute__((weak)) int _read(int file, char *ptr, int len)
{
  (void)file;
  int DataIdx;

  for (DataIdx = 0; DataIdx < len; DataIdx++)
  {
    *ptr++ = __io_getchar();
  }

  return len;
}

__attribute__((weak)) int _write(int file, char *ptr, int len)
{
  (void)file;
  int DataIdx;

  for (DataIdx = 0; DataIdx < len; DataIdx++)
  {
    __io_putchar(*ptr++);
  }
  return len;
}
void ITM_enable(void) {
#define WWORD(x) *((__IO uint32_t *)(x))
#define SWO_BASE (0x5C003000UL)
#define SWTF_BASE (0x5C004000UL)
    uint32_t SWOSpeed = 7500000; /* [Hz] we have 2 Mbps SWO speed in ST-Link SWV viewer if we select 400000000 Hz core clock */
    uint32_t SWOPrescaler = (SystemCoreClock / SWOSpeed) - 1; /* divider value */

    //enable debug clocks
    DBGMCU->CR = 0x00700000; //enable debug clocks

    //UNLOCK FUNNEL
    //SWTF->LAR unlock

    //SWO->LAR unlock
    WWORD(SWO_BASE + 0xFB0) = 0xC5ACCE55; //unlock SWO
    
    if (WWORD(SWO_BASE + 0xFB4) & 0x00000002) {
        while(1); // blocked from access
    }
    //SWO divider setting
    //This divider value (0x000000C7) corresponds to 400Mhz core clock
    //SWO->CODR = PRESCALER[12:0]
    WWORD(SWO_BASE + 0x010) = (WWORD(SWO_BASE + 0x010) & 0xFFFFF000) | SWOPrescaler; //clock divider
    WWORD(SWO_BASE + 0x0F0) = (WWORD(SWO_BASE + 0x0F0) & 0xFFFFFFF0) | 0x00000002; //set to NRZ
    /* WWORD(SWO_BASE + 0x300) = (WWORD(SWO_BASE + 0x300) & 0xFFFFFFF0) | 0x00000008; // */

    WWORD(SWTF_BASE + 0xFB0) = 0xC5ACCE55; //unlock SWTF
    WWORD(SWTF_BASE + 0x000) = 0x00000003; //enable port 0 and 1

    // enable poer
    WWORD(0x580244E0) |= 0x00000002;
    WWORD(0x58020400) = (WWORD(0x58020400) & 0xffffff3f) | 0x00000080;
    WWORD(0x58020408) |= 0x00000080;
    WWORD(0x58020420) &= 0xffff0fff;

}

void DWT_enable(void) {
    CoreDebug->DEMCR |= CoreDebug_DEMCR_TRCENA_Msk;
    DWT->CTRL |= DWT_CTRL_CYCCNTENA_Msk;    
}
#endif

static void rounder_cb(lv_event_t *e)
{
    lv_area_t *area = lv_event_get_param(e);

    /* Round the height to the nearest multiple of 8 */
    area->x1 = (area->x1 & ~0x1);
    area->x2 = (area->x2 | 0x1);
}

CRITICAL void lv_setup(void) {
    {
#ifdef PLATFORM_SIM
    display = lv_sdl_window_create(DISPLAY_WIDTH, DISPLAY_HEIGHT);
#else
    display = lv_display_create(DISPLAY_WIDTH, DISPLAY_HEIGHT);
#ifdef DIRECT
#ifdef PARTIAL
    lv_display_set_buffers(display, pixelbuffer, pixelbuffer2, (COLOR_SIZE * DISPLAY_WIDTH * 512) / 2, LV_DISPLAY_RENDER_MODE_PARTIAL);
#else
    lv_display_set_buffers(display, framebuffer, NULL, (COLOR_SIZE * DISPLAY_HEIGHT * DISPLAY_WIDTH), LV_DISPLAY_RENDER_MODE_DIRECT);
#endif
#else
  #if PIXEL_BUFFER_SIZE == (DISPLAY_WIDTH * COLOR_SIZE * DISPLAY_HEIGHT)
    lv_display_set_buffers(display, pixelbuffer, NULL, PIXEL_BUFFER_SIZE, LV_DISPLAY_RENDER_MODE_DIRECT);
  #else
    lv_display_set_buffers(display, pixelbuffer, pixelbuffer2, PIXEL_BUFFER_SIZE, LV_DISPLAY_RENDER_MODE_PARTIAL);
  #endif
#endif
    lv_display_set_flush_cb(display, lcd_lvgl_flush);
#endif


        lv_display_add_event_cb(display, rounder_cb, LV_EVENT_INVALIDATE_AREA, display);
        // ticks
#if !defined(STM32H743)
        lv_tick_set_cb(&timer_cb);
#endif
    }
}
#ifdef PROFILE
// send on itm port 1
void flush_cb(const char *buffer) {
    int l = strlen(buffer);
    while(l--) {
        while(ITM->PORT[1U].u32 == 0UL) __NOP();
        ITM->PORT[1U].u8 = (uint8_t)*buffer++;
    }
}
void SetupProfiler(void) {
    clock_setup_us_source();
    lv_profiler_builtin_config_t config;
    lv_profiler_builtin_config_init(&config);
    config.tick_per_sec = 1000000; /* One second is equal to 1000000000 nanoseconds */
    config.tick_get_cb = clock_us;
    config.flush_cb = flush_cb;
    lv_profiler_builtin_init(&config);
}
#endif
extern uint32_t frames;

int CRITICAL main(void)
{
    /* memcpy(&_sitcmram, &_siitcmram, (uint32_t)&_eitcmram - (uint32_t)&_sitcmram);  */
    system_clock_config();

#if defined(SWO)
    // enable swo
    ITM_enable();
    printf("---------------------------------------- LOG START ----------------------------------------------\n");
#endif

#if defined(SEMIHOSTING) && !defined(PLATFORM_SIM) && !defined(SWO)
  	initialise_monitor_handles();
#endif
    delay_init();
    lv_init();
#ifdef MEMPOOL
    /* lv_mem_add_pool(mempool, MEMPOOL); */
    /* lv_obj_t *obj_arry heap_caps_malloc(sizeof(lv_obj_t) * array_size, HEAP_CAPS_SPIRAM); */
#endif
#ifdef PROFILE
    SetupProfiler();
#endif
    lv_setup();
#ifdef PLATFORM_SIM
    eeprom_init();                          // initialize the eeprom for data storage
    uart_init(57600, 230400);                       // initialize comms
    gui_init();
#endif
    
    controls_init();                        // init adc and buttons 
    power_enable();
   

    lcd_init();                             // attempt to initialize the lcd peripherals
    lcd_backlight(50);
    if (!lcd_start()) {
#ifndef DEBUG
        led_red(1);
        led_blue(1);
        led_green(0);
        delay_ms(500);
        NVIC_SystemReset();                            // start lcd init sequence
#endif
    }
    crc_init();                             // crc init if HW unit
    eeprom_init();                          // initialize the eeprom for data storage
    clock_init();                           // clouck source (if available)
    
    button_release(BUTTON_ID_POWER, 2000);   // ignore inputs for a while
    button_release(BUTTON_ID_DOWN, 2000);   // ignore inputs for a while
    button_release(BUTTON_ID_UP, 2000);   // ignore inputs for a while

#ifndef PLATFORM_SIM
    uart_init(57600, 230400);                       // initialize comms
#ifdef CAN_ENABLED
    can_init();                             // init can
#endif
    gui_init();                             // start lvgl and setup screen
#endif
    comm_send_controller_settings();
    comm_send_display_settings();  
    comm_send_display_status();  

#ifndef LIGHT_SENSOR_ENABLED
    lcd_backlight(100);
#endif

#ifdef TOUCH_ENABLED
    touch_init();
#endif
    uint32_t mcconf_timeout = 0;
#if MONITOR && DEBUG
#endif
    lv_timer_handler();
#if (!defined(DEBUG) || DEBUG == 0) && !defined(PLATFORM_SIM)
#if defined(STM32H743)
#endif
#endif
#ifdef BT_UART_ENABLED
    bt_send_init(1);
    uint32_t x = HAL_GetTick();
#endif
#ifndef DEBUG
    init_iwdt();
#endif

    LV_LOG_INFO("Starting main loop");
    while(1) {
#if PLATFORM_SIM && LVGL_VERSION_MAJOR == 9
        SDL_Delay(5);
#endif
        comm_update();
        button_presses();
        gui_update();                                           // update gui data
        auto_lights();
        /* lv_timer_handler(); */
        uint32_t m = lv_timer_handler();
        delay_ms(m > CYCLE_DELAY_LIMIT ? CYCLE_DELAY_LIMIT : m);
#if (!defined(DEBUG) || DEBUG == 0) && !defined(PLATFORM_SIM)
#if defined(STM32H743)
    
#else
        wdt_counter_reload();
#endif
#endif
        // shutdown check
        if (settings.shutdown_timer > 0 && HAL_GetTick() - shutdown_timer > (((uint32_t) settings.shutdown_timer) * 60000)) {
            power_disable();
        }

        // make sure motor configuration is up to date in case of VESC
#if (UART_COMM == UART_COMM_VESC) || defined(CAN_ENABLED)
        if ((!mconf_actual || !mconf_updated) && HAL_GetTick() - mcconf_timeout > 5000) {
            if (!mconf_actual) {
                LV_LOG_INFO("MCCONF not received, attempting");
                // reinit CAN
                can_deinit();
                delay_ms(1);
                can_init();
                delay_ms(1);
                comm_vesc_ping();
                comm_send_controller_settings();
            }
            if (mconf_actual && !mconf_updated) {
                LV_LOG_INFO("MCCONF not stored, updating");
                comm_send_display_status();
            }
            mcconf_timeout = HAL_GetTick();
        }
#endif
        if (HAL_GetTick() - x > 250) {
            /* bt_send((uint8_t *) "AT\r\n", 4); */
            x = HAL_GetTick();
        }
#ifndef DEBUG
        feed(); // feed watchdog
#endif
    }
}

#if !defined(PLATFORM_SIM)
#if defined(STM32H743)
CRITICAL void WAKEUP_PIN_IRQHandler(void) {
    while(1);
}
CRITICAL void WWDG_IRQHandler (void) {
    NVIC_SystemReset();
}
#else
CRITICAL void WWDT_IRQHandler(void) {
    NVIC_SystemReset();
}
#endif
#endif

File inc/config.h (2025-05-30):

#ifndef __CONFIG_H__
#define __CONFIG_H__

#define DIRECT      // use direct
#define PARTIAL     // use direct processing but partial buffers
                    // disable both for partial buffers and full frame buffer
#define COLOR_SIZE 2 
#define C24_8(c, d)         ((c << 8) | (d * 256))

#define DISPLAY_WIDTH   320
#define DISPLAY_HEIGHT  480

#define TEMPERATURE_FILTER_SHIFT 4
#define VOLTAGE_FILTER_SHIFT 4
#define SPEED_FILTER_SHIFT 2
#define POWER_FILTER_SHIFT 2

#define TOUCH_ENABLED
#define LIGHT_SENSOR_ENABLED
#define BT_UART_ENABLED

#ifdef DEBUG
 #if defined(AT32F435) || defined(STM32H743)
  #define PIXEL_BUFFER_LINES 128
 #else
  #define PIXEL_BUFFER_LINES 20
 #endif
#else

 #ifdef PLATFORM_LCD8
  #if defined(AT32F415)
   #define PIXEL_BUFFER_LINES 22 // lower if more mem is required for lvgl
  #elif defined(AT32F435)
   #define PIXEL_BUFFER_LINES DISPLAY_HEIGHT
  #endif
 #else
  #if defined(STM32H743)
   #define PIXEL_BUFFER_LINES 128   
  #else
   #define PIXEL_BUFFER_LINES 32 // reduces tearing if multiple of 32
  #endif
 #endif
#endif

#define PIXEL_BUFFER_SIZE (PIXEL_BUFFER_LINES * COLOR_SIZE * DISPLAY_WIDTH)

#define REFRESH_INTERVAL 33 // refresh interval in ms

#ifdef PLATFORM_custom
 #define EEPROM_SIZE 2048
#else
 #define EEPROM_SIZE 512 // device has a 2 page eeprom
#endif
/**
 * default values
 */
#define POWER_MAX 500
#define POWER_REDLINE 300
#define POWER_MIN -400

#define SPEED_MAX       35
#define SPEED_REDLINE   25
#define SPEED_MAX_ASSIST 28

#define BATTERY_MIN 21000
#define BATTERY_MAX 29400

#define GRAPH_DURATION 5
#define GRAPH_SHIFT 1
#define GRAPH_MAX 30

#define ASSIST_LEVELS 9
#define ASSIST_DEFAULT 0
#define WHEEL_CIRCUMFENCE 216
#define PAS_TIMEOUT 8000
#define PAS_RAMP 1600
#define REGEN_CURRENT 15000

#define SHUTDOWN_TIMER_DEFAULT 10

#define NOTIFICATION_TIMEOUT 5000

#define CYCLE_DELAY_LIMIT 5             // max amount of delay before lv_timer triggers again, keep at ~5ms for maximum responsiveness
/*
 * if you install a external 32khz crystal the ertc can work
 * I chose a bog standard one with 2 * 5.6pF caps.
 * to keep it running the battery will drain.
 * Adding a tiny battery will not work as the drain current is ~10mA and it's neigh impossible to
 * detect the power signal in the comperator on PA4 due to it being in the single digit mV range.
 * I've tried changing the resistors but this does not result in significant changes. I probably
 * do not understand the circuit and since no device is ever sold with an RTC I guess the original
 * developers didn't either.
 */
#define LEXT_INSTALLED 1

// change to not draw controller mode
#define DRAW_CONTROLLER_MODE

// archtecture specifics

#define RAMFAST
#define RAMHIGH
#define CRITICAL

#if defined(AT32F415)
/*
 * OC will use 200mhz and an external crystal. 
 * I added an 8MHz crystal and two 17pF caps.
 */
  #define OC // overclock to 200mhz, which is the maximum. Higher values will result in 200mhz but every other calculation is broken

  #ifdef OC
   #define CLOCK_SOURCE         CRM_CLOCK_SOURCE_HEXT  // you need a stable crystal
   #define CLOCK_SOURCE_DIV     CRM_PLL_SOURCE_HEXT 
   #define CLOCK_SOURCE_FLAG    CRM_HEXT_STABLE_FLAG
   #define FLASH_WAIT_CYCLES    FLASH_WAIT_CYCLE_3 // 3 might work, ymmv
   #define PLL_MULTIPL          CRM_PLL_MULT_25    // 200mhz
   #define AHB_DIVIDER          CRM_AHB_DIV_1      // 200mhz
   #define APB2_DIVIDER         CRM_APB2_DIV_2     // 100mhz
   #define APB1_DIVIDER         CRM_APB1_DIV_2     // 100mhz
   #define EFFECTIVE_CLOCK      (8000000)

  #else
   #define CLOCK_SOURCE         CRM_CLOCK_SOURCE_HICK
   #define CLOCK_SOURCE_DIV     CRM_PLL_SOURCE_HICK
   #define CLOCK_SOURCE_FLAG    CRM_HICK_STABLE_FLAG
   #define FLASH_WAIT_CYCLES    FLASH_WAIT_CYCLE_4 // 
   #define PLL_MULTIPL          CRM_PLL_MULT_36    // 144mhz
   #define AHB_DIVIDER          CRM_AHB_DIV_1      // @cpu
   #define APB2_DIVIDER         CRM_APB2_DIV_2     // 72mhz
   #define APB1_DIVIDER         CRM_APB1_DIV_2     // 72mhz
   #define EFFECTIVE_CLOCK      (4000000)
  #endif

  #define TIMER_FREQ(x)        (\
            (\
                (2 * (EFFECTIVE_CLOCK) * (1 + PLL_MULTIPL)) / ((1 + (APB2_DIVIDER >> 2)) * (1 + (AHB_DIVIDER >> 3)) * 10) \
            ) / x)

  #include "at32f415.h"
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

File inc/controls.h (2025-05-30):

#ifndef __CONTROLS_H__
#define __CONTROLS_H__

#include "lvgl.h"


#define BUTTON_MEASURE_PERIOD   50 // measure every 100ms
#define BUTTON_ACTIVE_PERIOD    200 // active period 300ms
#define BUTTON_HOLD_PERIOD      1000 // active period 300ms
#define BUTTON_LONG_PRESS_TIME  1000
#define BUTTON_TIMEOUT          10000
#define BUTTON_DEBOUNCE_TIME    BUTTON_MEASURE_PERIOD + 10

#define BUTTON_COUNT (BUTTON_ACTIVE_PERIOD / BUTTON_MEASURE_PERIOD)
#define BUTTON_HOLD (BUTTON_HOLD_PERIOD / BUTTON_MEASURE_PERIOD)

typedef struct {
    uint16_t temperature_int;
    uint16_t voltage_mcu;
    uint16_t voltage_battery;
    union {
        uint16_t temperature_ext;
        uint16_t up_button;
    };
    union {
        uint16_t nc_button; // can be used as light detector?
        uint16_t light_level;
    };
    uint16_t power_button; // normally not read
    uint16_t down_button; // normally not read
} adc_data_t;

void controls_init(void);
void button_release(uint8_t id, uint32_t backoff);
uint8_t buttons_pressed(void);

void reset_all_buttons(void);

int32_t voltage_ebat(void);
int32_t voltage_mcu(void);
int32_t voltage_bat(void);

int32_t int_temp(void);
int32_t ext_temp(void);
int32_t internal_temperature(void);
int32_t light_level(void);
void auto_lights();

void power_enable(void);
void power_disable(void);

void led_red(int state);
void led_green(int state);
void led_blue(int state);

int led_blue_state(void);
int led_green_state(void);
int led_red_state(void);

#define LIGHTS_DISABLED 0
#define LIGHTS_ENABLED 1

#define BUTTON_ID_UP        0
#define BUTTON_ID_DOWN      2 
#define BUTTON_ID_POWER     4
#define BUTTON_ID_NC        6

#define BUTTON_RELEASED     0
#define BUTTON_DOWN         1 
#define BUTTON_PRESSED      2
#define BUTTON_LONG_PRESSED 3

#define BUTTON_STATE(x, y)     (y << x)
#define BUTTON_MASK(x)         (0x3 << x)

#endif // __CONTROLS_H__

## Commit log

2025-02-22 Fixed wrong VDD/+5V lines
2025-03-05 Initial source commit, debug only, includes eeprom read/write and basic adc&button tooling. LCD does not function yet.
2025-03-05 lcd backlight with tim3 pwm
2025-03-07 Setup of sim and ugui
    * Note: 565 is broken in ugui, needs the changes to properly work e.g.
    with 8bit fonts
    [config.h, controls.h, eeprom.c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]
2025-03-21 Switch to lvgl v8.4 and initial display
2025-04-16 Basic dma working, but issues and broken eeprom i2c
    [comm.c, config.h, eeprom.c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]
2025-04-16 Working version, with DMA transfer option (a bit broken for now)
    [config.h, eeprom.c, lcd.c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]
2025-04-16 Different filter settings for voltage and temperature
2025-04-17 Some fixes to stuck updates and added controls in sim
    [gui.c, main.c, uart.c]
2025-04-19 Actually switch to 448k
2025-05-17 Workingish at32f435
    [jlink-at32f435.cfg]
2025-05-25 Working VESC setup, removed default theme for space
    [jlink-at32f435.cfg]
2025-05-28 bugfixes, sim fixes and some minor changes
    [comm.c, config.h, controls.h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]
2025-07-18 Start of own custom pcb and stm32h743 implementation with dma2d and 24/18bit color
2026-06-11 Changed default values for waiting for buttons at start
2026-06-23 Added PCB files
    [display.kicad_pcb, display.kicad_sch, display_connectivity.kicad_sch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]
2026-06-23 Saved pcb
    [display_power.kicad_sch]
